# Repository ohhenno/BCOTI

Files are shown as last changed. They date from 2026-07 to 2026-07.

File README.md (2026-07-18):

# BCOTI (Budget-Clip-On-Thermal-Imager Remix**)
The current version uses a 256x192@12um sensor with a 4mm OR 9.1mm lens. This combined with the LZE039 and 10mm or 25mm DCX lens.









# BCOTI Fork — Parts List

Quick BOM with EU and US buy links per part.

| Part | Price | Description | EU Shop | US Shop |
|---|---|---|---|---|
| Thermal Core (Mini2, 256, 9.1mm or 4mm) | ~189€ | Thermal sensor core | [AliExpress](https://s.click.aliexpress.com/e/_ooB5Db9) | [Alibaba (Hdaniee)](https://www.alibaba.com/product-detail/HDANIEE-Series-Thermal-Imaging-Camera-Module_1601290252342.html) |
| 0.39" OLED Display | $110 / 98€ | Display + AV driver board | [AliExpress](https://s.click.aliexpress.com/e/_oCvDQUx) | [AliExpress US](https://www.aliexpress.us/item/3256809119244467.html) |
| ESP32-C3 | $1 / 2.6€ | Main controller board | [AliExpress](https://s.click.aliexpress.com/e/_oCkdBST) | [AliExpress US](https://www.aliexpress.us/item/3256808855552297.html) |
| 5V Boost Converter | $2 | Steps battery voltage up to 5V | [AliExpress](https://www.aliexpress.com/item/32800430445.html) | [Amazon](https://www.amazon.com/dp/B0836J8LR4) |
| 18350 Battery | ~$7 / ~3.50€ | Power source, button-top preferred | [AliExpress](https://de.aliexpress.com/item/1005006794197560.html) | [Amazon](https://www.amazon.com/Nitecore-NI18350A-700mAh-Rechargeable-Battery/dp/B00ZASC06Y) |
| Battery Contacts | ~3€ (50pc) / ~$8 (10pc) | Spring terminals for battery holder | [AliExpress](https://www.aliexpress.com/i/1005002703811117.html) | [Amazon (Keystone)](https://www.amazon.com/KEYSTONE-BATTERY-SPRING-CONTACT-pieces/dp/B00LPOWFGM) |
| Rotary Pot 10k (thumbwheel) | ~$7 (5pc) | Brightness/scroll control | [AliExpress](https://www.aliexpress.com/w/wholesale-10k-rotary-potentiometer.html) | [Amazon](https://www.amazon.com/10K-Ohm-Thumbwheel-Potentiometer-Pack/dp/B015IQP2I0) |
| Momentary Buttons (assortment) | ~$9 (200pc) | Mixed-size push buttons for menu/power | [AliExpress](https://www.aliexpress.com/w/wholesale-momentary-push-button.html) | [Amazon](https://www.amazon.com/Oiyagai-200-Pcs-Tactile-Momentary-Assortment/dp/B07DG3VGZT) |
| M2.5 Allen Bolt (assortment) | ~16€ (140pc) / ~$10 (310pc) | Hex socket screws, mixed lengths | [AliExpress](https://www.aliexpress.com/item/32823580440.html) | [Amazon](https://www.amazon.com/Stainless-Steel-Socket-Screw-Assortment/dp/B0116RIAO8) |
| M2.5 Heat Set Inserts | ~10€ (100pc) / ~$8 (50pc) | Threaded brass inserts for 3D-printed housing | [CNCKitchen](https://cnckitchen.store/products/gewindeeinsatz-threaded-insert-m2-5-standard-100-stk-pcs) | [Amazon (initeq)](https://www.amazon.com/initeq-M2-5-0-45-M2-5-0-4-Threaded-Printing/dp/B077CJQ3J4) |
| Silicone Wire (30AWG) | ~2€ (10m) / ~$10 (6-color kit) | Internal wiring, multiple colors | [AliExpress](https://www.aliexpress.com/item/32719731059.html) | [Amazon](https://www.amazon.com/TUOFENG-30awg-Stranded-Wire-Kit/dp/B07G2SWB19) |
| 5mmD 25mmF DCX Lens | ~40€ / $41.61 | Periscope objective lens | [Edmund Optics EU](https://www.edmundoptics.eu/p/5mm-dia-x-25mm-fl-uncoated-double-convex-lens/18171/) | [Edmund Optics US](https://www.edmundoptics.com/p/5mm-dia-x-25mm-fl-uncoated-double-convex-lens/18171/) |
| 5x5x5mm Right-Angle Prism | 1.99€ | Periscope reflector | [AliExpress](https://s.click.aliexpress.com/e/_oBrJOrZ) ([backup](https://www.aliexpress.com/item/4001089104491.html)) | [AliExpress US](https://www.aliexpress.us/item/2255799866264049.html) |
| USB-C Connector Breakout | 2.25€ | Internal USB-C wiring / low-profile helmet cable | [AliExpress ("TYPE-C male 4P")](https://s.click.aliexpress.com/e/_oCcvkCx) | [Amazon (Treedix)](https://www.amazon.com/Treedix-Type-C-Breakout-Connector-Converter/dp/B096M2HQLK) |
| USB-C Port | 1.49€ | Charging port, "4P Black" variant | [AliExpress](https://www.aliexpress.com/w/wholesale-usb-type-c-4-pin.html) | [AliExpress US](https://www.aliexpress.us/item/1005005768848819.html) |

**Notes**
- AliExpress "EU" links use the standard `.com`/`s.click` storefront (EU warehouse pricing); "US" links use `aliexpress.us` where available for faster US shipping.
- Assortment kit prices are for the full kit, not per piece — you'll only need a handful of pieces from each.

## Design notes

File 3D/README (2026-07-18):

Choose the right version you are building as there are some differences. Make sure your Mini camera lens is correct and the DFX lens you buy match!!!

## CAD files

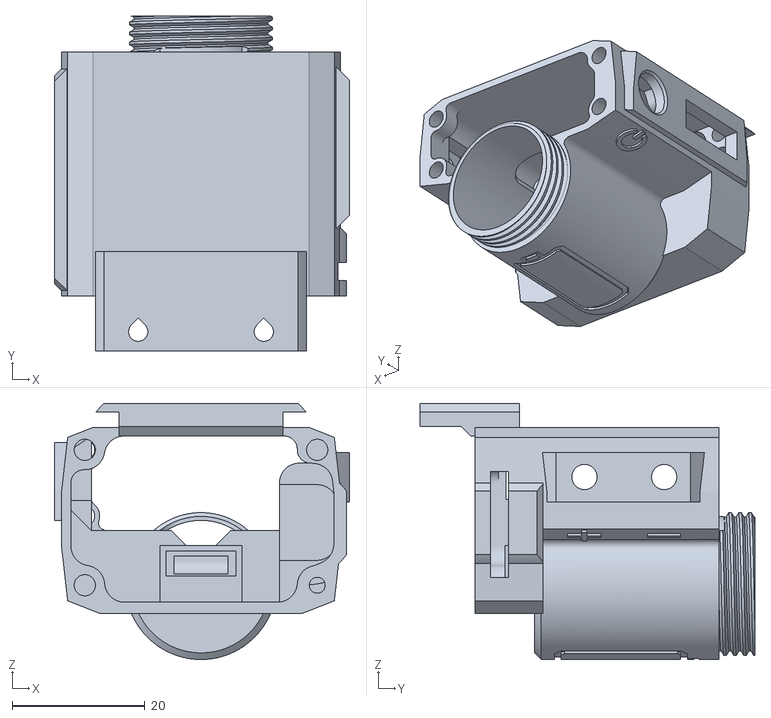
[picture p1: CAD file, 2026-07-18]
3D/mini256 9mm (narrow FOV)/main body 9mm lens.stl
44.5 x 50.5 x 38.6

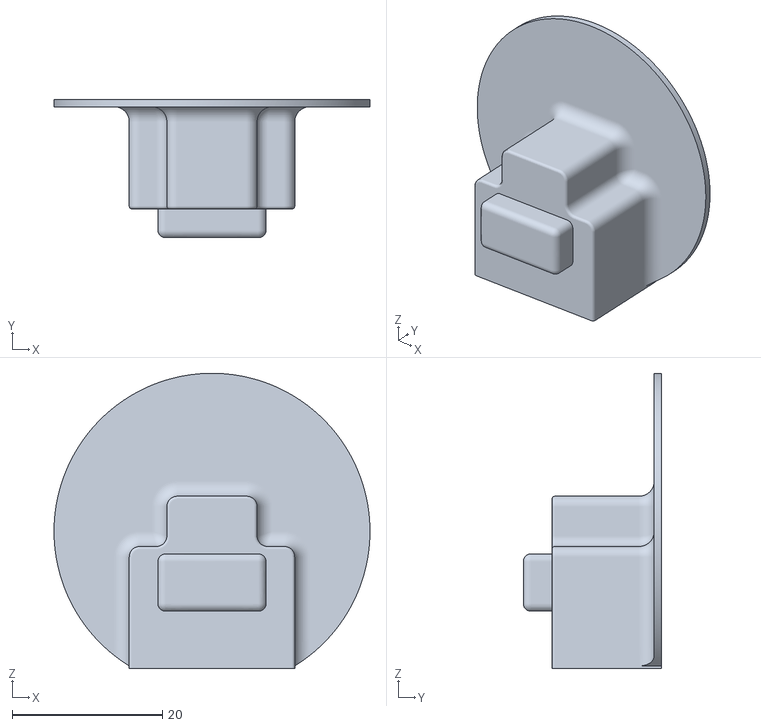
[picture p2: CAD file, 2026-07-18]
3D/mini256 4mm (wide FOV)/periscope cover (draft) 10mmF.stl
42.0 x 18.4 x 39.3

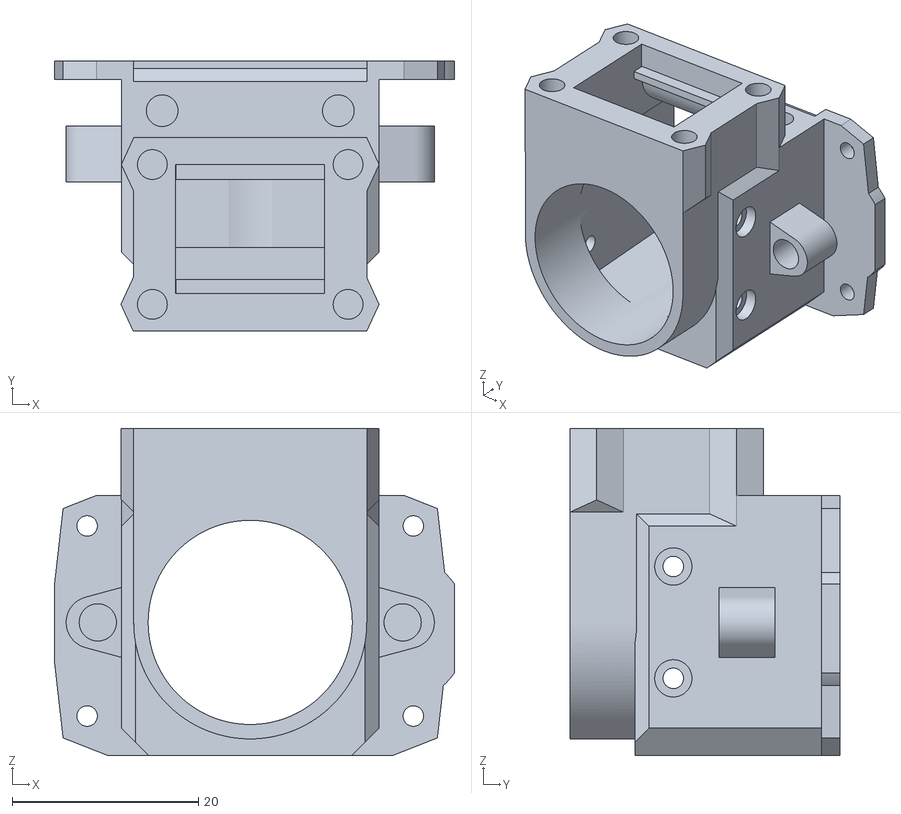
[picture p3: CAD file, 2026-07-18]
3D/mini256 9mm (narrow FOV)/front body 9mm.stl
42.9 x 29.0 x 35.1

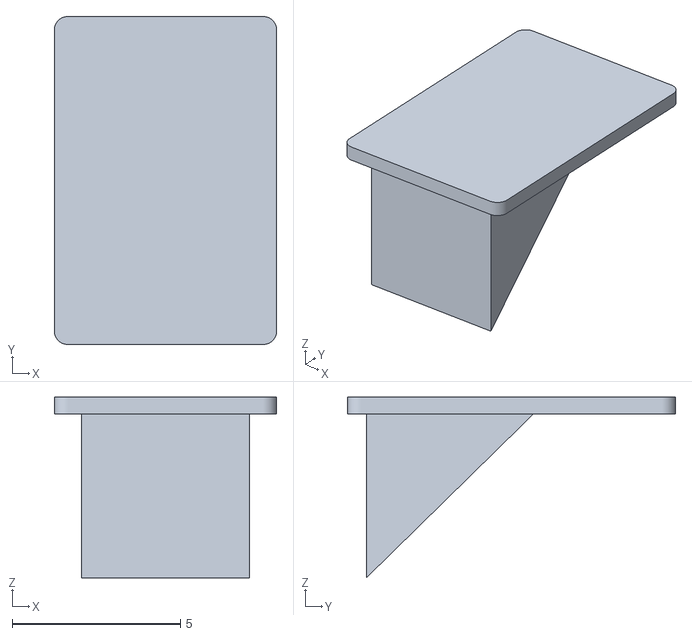
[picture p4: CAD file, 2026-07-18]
3D/mini256 4mm (wide FOV)/periscope hat.stl
6.60 x 9.74 x 5.36

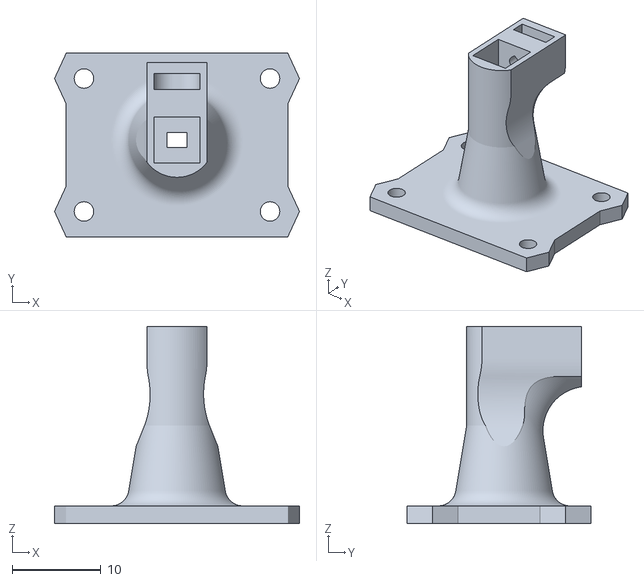
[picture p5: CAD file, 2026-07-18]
3D/mini256 9mm (narrow FOV)/periscope original 25mmF.stl
27.6 x 20.8 x 22.2

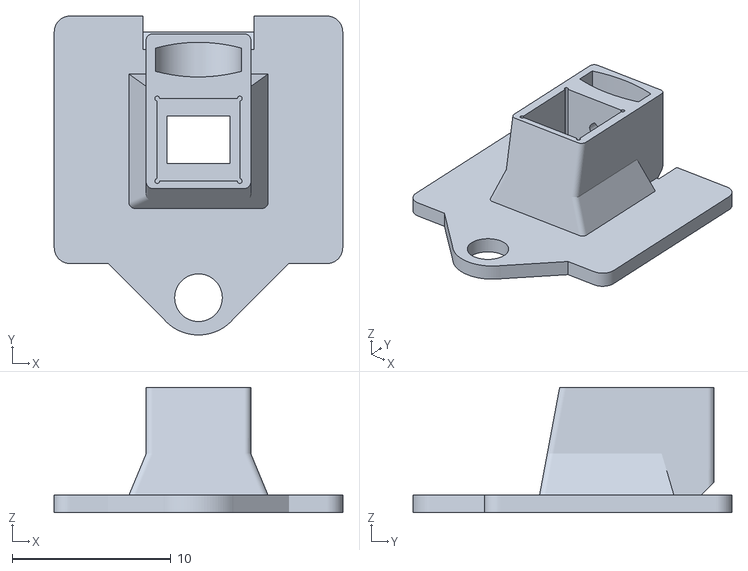
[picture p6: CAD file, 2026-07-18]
3D/mini256 4mm (wide FOV)/periscope 10mmF FOV.stl
18.2 x 20.1 x 7.89

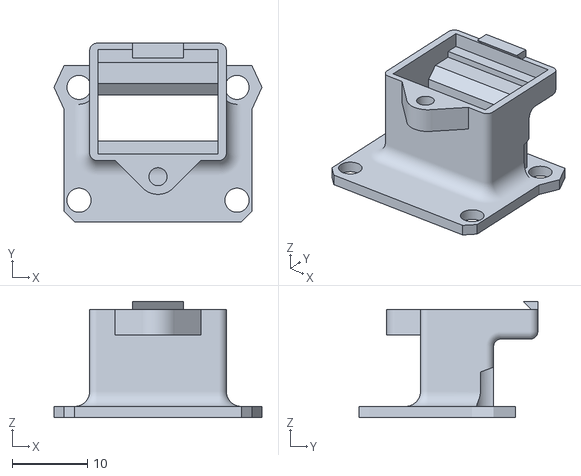
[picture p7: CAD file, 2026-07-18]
3D/mini256 4mm (wide FOV)/periscope spacer 10mmF FOV.stl
27.6 x 23.8 x 15.5

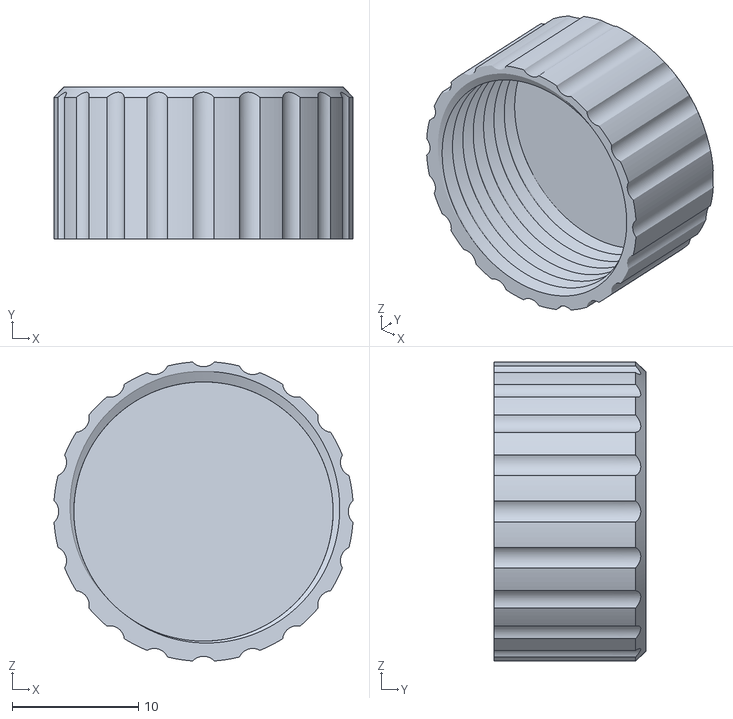
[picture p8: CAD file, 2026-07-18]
3D/mini256 9mm (narrow FOV)/bat cap.stl
23.7 x 12.0 x 23.7

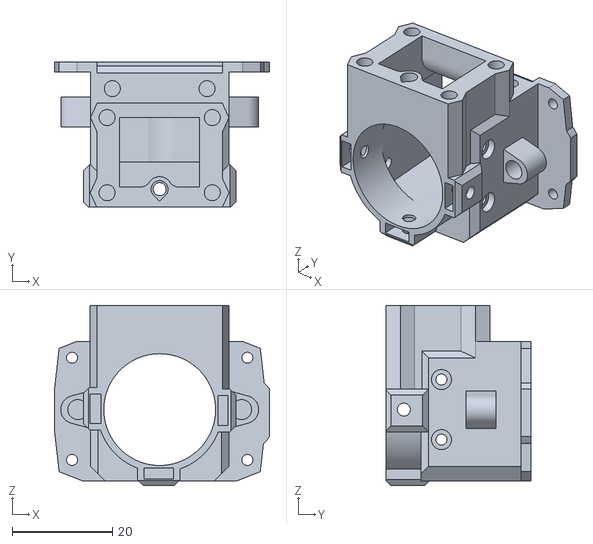
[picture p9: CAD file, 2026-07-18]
3D/mini256 4mm (wide FOV)/front body 4mm lens.stl
42.9 x 29.0 x 36.0

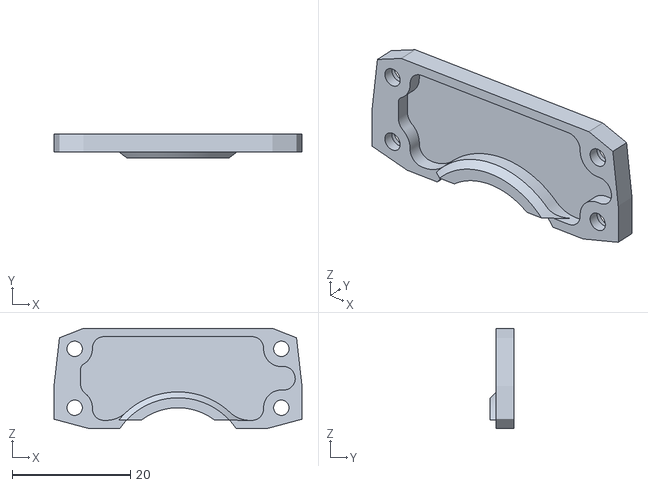
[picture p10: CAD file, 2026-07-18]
3D/mini256 9mm (narrow FOV)/back cover.stl
42.0 x 4.00 x 17.0

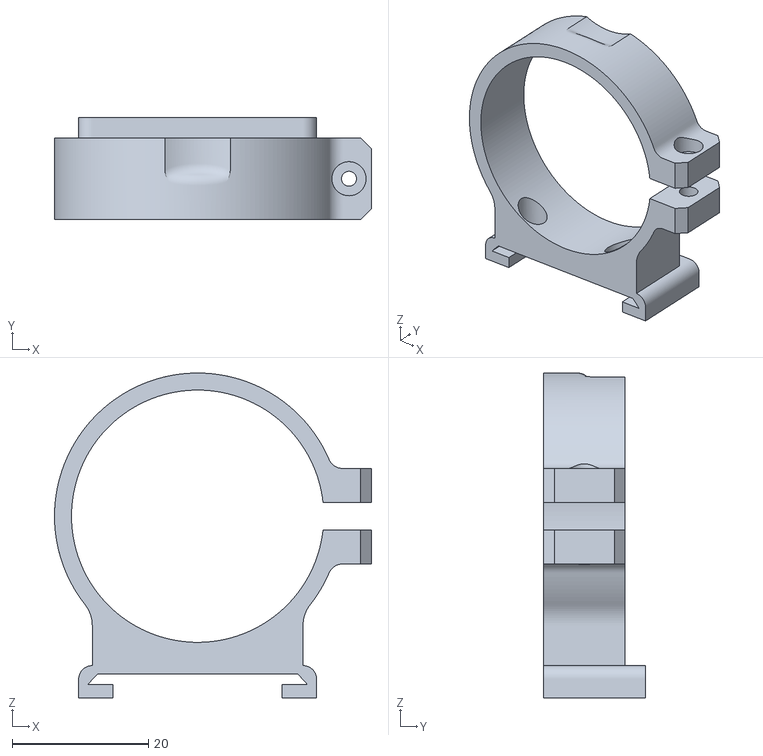
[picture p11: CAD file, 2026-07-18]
3D/mini256 9mm (narrow FOV)/lens attach.stl
46.5 x 15.0 x 47.7

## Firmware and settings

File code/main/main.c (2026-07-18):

#include <stdio.h>
#include <stdlib.h>
#include <stdint.h>
#include <stdbool.h>

#include "freertos/FreeRTOS.h"
#include "freertos/task.h"

#include "driver/gpio.h"
#include "driver/adc.h"

#include "nvs.h"
#include "nvs_flash.h"

#include "esp_wifi.h"
#include "esp_event.h"
#include "esp_netif.h"
#include "esp_http_server.h"

#include "Mini2.h"

// ============================================================
// WiFi Access Point settings
// Connect to this network, then open http://192.168.4.1
// ============================================================
#define WIFI_AP_SSID      "BCOTI-QC"
#define WIFI_AP_PASS      "thermal123"   // min 8 chars for WPA2
#define WIFI_AP_CHANNEL   1
#define WIFI_AP_MAX_CONN  4

static uint32_t last_click_time = 0;
static bool waiting_for_second_click = false;
static bool swallow_next_release = false;

static uint32_t mode_change_count = 0;
static uint32_t nuc_count = 0;
static uint32_t pan_count = 0;
static uint32_t brightness_count = 0;

static bool test_up = false;
static bool test_down = false;
static bool test_left = false;
static bool test_right = false;
static bool test_center = false;

static bool test_zoom = false;
static bool test_mode = false;
static bool test_nuc = false;
static bool test_brightness = false;

static int adc_min = 4095;
static int adc_max = 0;

#define DOUBLE_WINDOW_MS 400

#define PIN_CENTER     GPIO_NUM_0
#define PIN_LEFT       GPIO_NUM_3
#define PIN_UP         GPIO_NUM_10
#define PIN_RIGHT      GPIO_NUM_9
#define PIN_DOWN       GPIO_NUM_8

#define PIN_UART_TX    GPIO_NUM_1
#define PIN_UART_RX    GPIO_NUM_2

#define PAN_REPEAT_MS      40
#define TUNE_REPEAT_MS     60
#define SAVE_DELAY_MS    2000
#define NUC_PRESS_MS     3000
#define CENTER_PRESS_MS  6000

#define DEBOUNCE_MS        30
#define DPAD_LOCKOUT_MS   150

#define BRIGHT_MIN_INTERVAL_MS 150
#define BRIGHT_DEADBAND         3

// "Double-max sweep" gesture: turn the brightness knob to its extreme,
// let it fall away, then hit that same extreme again within the window
// -- this cycles the active mode/preset, same trick as the center-button
// double click. Thresholds are on raw ADC counts (pre direction-reversal),
// so ENTER is the low-raw / max-brightness end. This runs off a fast,
// lightly-smoothed reading (see adc_fast below) rather than the heavily
// filtered adc_filtered used for brightness output -- that filter has a
// multi-sample settle time that was eating quick flicks to the end.
#define KNOB_GESTURE_ENTER_RAW   500    // fast-filtered ADC <= this = "at max"
#define KNOB_GESTURE_EXIT_RAW    700    // must rise above this to re-arm
#define KNOB_GESTURE_WINDOW_MS  1200    // whole gesture must land in this window

#define ZOOM_MIN      10      // 1.0x
#define ZOOM_MAX      20      // 2.0x
static uint8_t zoom_level = 10;

#define PAN_STEP            1

#define ALIGN_CENTER_X   128
#define ALIGN_CENTER_Y    96

#define ALIGN_X_MIN      116
#define ALIGN_X_MAX      140

#define ALIGN_Y_MIN       87
#define ALIGN_Y_MAX      105

static Mini2_t cam;

typedef struct
{
    enum PseudoColor pseudo_color;
    enum SceneMode scene_mode;
    uint8_t contrast;
    uint8_t edge;
    uint8_t detail;
} preset_t;

static preset_t presets[3] =
{
    {
        .pseudo_color = WHOT,
        .scene_mode = Highlight,
        .contrast = 100,
        .edge = 1,
        .detail = 55
    },

    {
        .pseudo_color = WHOT,
        .scene_mode = HighContrast,
        .contrast = 100,
        .edge = 1,
        .detail = 55
    },

    {
        .pseudo_color = WHOT,
        .scene_mode = Outline,
        .contrast = 100,
        .edge = 1,
        .detail = 50
    }
};

// Default startup configuration is preset index 2 (Outline mode).
// This only matters on a fresh boot with no saved NVS preference --
// load_settings() will override it with whatever preset was last
// saved, if any.
static uint8_t active_preset = 2;

// Live tuning state (what the camera is currently set to).
// Initialized from the active preset, edited live via the
// web UI, and copied back into presets[] on "save preset".
static uint8_t cur_contrast = 100;
static uint8_t cur_edge = 1;
static uint8_t cur_detail = 55;
static enum SceneMode cur_scene = Highlight;
static enum PseudoColor cur_palette = WHOT;
static enum FlipMode cur_flip = No_Flip;
static bool cur_cross = false;

static uint16_t zoom_x = 128;
static uint16_t zoom_y = 96;

static uint8_t brightness = 50;
static uint8_t last_brightness = 255;
static uint32_t last_brightness_cmd = 0;
static int adc_filtered = -1;

// Fast, lightly-smoothed ADC reading used only for the knob gesture below.
// adc_filtered (heavy 7/8 IIR) is deliberately slow so brightness output
// doesn't jitter; that same slowness meant it often never reached the
// gesture thresholds during a quick flick. This settles in ~1-2 samples
// instead of ~8, while still knocking down single-sample ADC noise.
static int adc_fast = -1;

// Knob "double-max sweep" mode-change gesture state.
// 0 = idle, 1 = hit max once (waiting for it to fall away),
// 2 = fell away (armed, waiting for the second max hit).
static uint8_t knob_gesture_stage = 0;
static uint32_t knob_gesture_deadline = 0;

// When false, the physical pot is ignored and the web
// brightness slider is in control.
static volatile bool knob_enabled = true;

static uint32_t last_pan_time = 0;
static uint32_t last_move_time = 0;

static bool settings_dirty = false;

static bool center_prev = false;
static uint32_t center_press_time = 0;
static uint32_t center_release_time = 0;

static uint32_t last_status_print = 0;

// ============================================================
// Web -> main loop mailbox. HTTP handlers ONLY write these;
// the main loop is the only task that talks to the camera
// UART, so commands stay serialized and paced.
// ============================================================
typedef struct
{
    volatile bool dirty;
    volatile int  val;
} wp_t;

static volatile int  web_x = -1;
static volatile int  web_y = -1;
static volatile int  web_z = -1;
static volatile bool web_xyz_dirty = false;

static wp_t wp_bright;
static wp_t wp_contrast;
static wp_t wp_detail;
static wp_t wp_edge;
static wp_t wp_scene;
static wp_t wp_palette;
static wp_t wp_flip;
static wp_t wp_cross;

static volatile bool web_nuc_req = false;
static volatile bool web_bgc_req = false;
static volatile int  web_preset_req = -1;
static volatile bool web_preset_save_req = false;
static volatile bool web_center_req = false;
static volatile bool web_save_req = false;
static volatile bool web_camsave_req = false;

static uint32_t millis(void)
{
    return xTaskGetTickCount() * portTICK_PERIOD_MS;
}

static int clampi(int v, int lo, int hi)
{
    if(v < lo) return lo;
    if(v > hi) return hi;
    return v;
}

// ------------------------------------------------------------
// Debounced button reader
// ------------------------------------------------------------
typedef struct
{
    gpio_num_t pin;
    bool stable;
    bool last_raw;
    uint32_t last_edge;
} btn_t;

static btn_t btn_up     = { .pin = PIN_UP };
static btn_t btn_down   = { .pin = PIN_DOWN };
static btn_t btn_left   = { .pin = PIN_LEFT };
static btn_t btn_right  = { .pin = PIN_RIGHT };
static btn_t btn_center = { .pin = PIN_CENTER };

static void btn_update(btn_t *b, uint32_t now)
{
    bool raw = (gpio_get_level(b->pin) == 0);

    if(raw != b->last_raw)
    {
        b->last_edge = now;
        b->last_raw = raw;
    }

    if(raw != b->stable &&
       (now - b->last_edge) >= DEBOUNCE_MS)
    {
        b->stable = raw;
    }
}

static void buttons_update(uint32_t now)
{
    btn_update(&btn_up, now);
    btn_update(&btn_down, now);
    btn_update(&btn_left, now);
    btn_update(&btn_right, now);
    btn_update(&btn_center, now);
}

static bool dpad_allowed(uint32_t now)
{
    if(btn_center.stable)
        return false;

    if((now - center_release_time) < DPAD_LOCKOUT_MS)
        return false;

    return true;
}

// ------------------------------------------------------------
// NVS persistence: position, presets, active preset
// ------------------------------------------------------------
static void save_position(void)
{
    nvs_handle_t nvs;

    if(nvs_open("thermal", NVS_READWRITE, &nvs) == ESP_OK)
    {
        nvs_set_u16(nvs, "x", zoom_x);
        nvs_set_u16(nvs, "y", zoom_y);
        nvs_commit(nvs);
        nvs_close(nvs);
    }
}

static void save_presets(void)
{
    nvs_handle_t nvs;

    if(nvs_open("thermal", NVS_READWRITE, &nvs) == ESP_OK)
    {
        nvs_set_blob(nvs, "presets", presets, sizeof(presets));
        nvs_set_u8(nvs, "preset", active_preset);
        nvs_commit(nvs);
        nvs_close(nvs);
    }
}

static void load_settings(void)
{
    nvs_handle_t nvs;

    zoom_x = 128;
    zoom_y = 96;

    if(nvs_open("thermal", NVS_READONLY, &nvs) == ESP_OK)
    {
        nvs_get_u16(nvs, "x", &zoom_x);
        nvs_get_u16(nvs, "y", &zoom_y);

        size_t len = sizeof(presets);
        preset_t tmp[3];

        if(nvs_get_blob(nvs, "presets", tmp, &len) == ESP_OK &&
           len == sizeof(presets))
        {
            memcpy(presets, tmp, sizeof(presets));
        }

        uint8_t p = 0;
        if(nvs_get_u8(nvs, "preset", &p) == ESP_OK && p < 3)
            active_preset = p;

        nvs_close(nvs);
    }

    if(zoom_x < ALIGN_X_MIN) zoom_x = ALIGN_X_MIN;
    if(zoom_x > ALIGN_X_MAX) zoom_x = ALIGN_X_MAX;

    if(zoom_y < ALIGN_Y_MIN) zoom_y = ALIGN_Y_MIN;
    if(zoom_y > ALIGN_Y_MAX) zoom_y = ALIGN_Y_MAX;
}

static void send_point_zoom(void)
{
    Mini2_set_point_zoom(
        &cam,
        zoom_x,
        zoom_y,
        zoom_level);

    test_zoom = true;
}

static void next_zoom_level(void)
{
    zoom_level++;

    if(zoom_level > ZOOM_MAX)
        zoom_level = ZOOM_MIN;

    printf("\nZOOM = %.1fx\n", zoom_level / 10.0f);

    send_point_zoom();
}

static void center_alignment(void)
{
    zoom_x = ALIGN_CENTER_X;
    zoom_y = ALIGN_CENTER_Y;

    printf("\nCENTER ALIGNMENT\n");

    send_point_zoom();

    pan_count++;

    settings_dirty = true;
    last_move_time = millis();
}

static void apply_preset(void)
{
    preset_t *p = &presets[active_preset];

    // Sync live tuning state to the preset
    cur_palette  = p->pseudo_color;
    cur_scene    = p->scene_mode;
    cur_contrast = p->contrast;
    cur_edge     = p->edge;
    cur_detail   = p->detail;

    printf("\nAPPLY PRESET %u\n", active_preset);

    Mini2_set_color_pallet(&cam, cur_palette);
    vTaskDelay(pdMS_TO_TICKS(50));

    Mini2_set_scene_mode(&cam, cur_scene);
    vTaskDelay(pdMS_TO_TICKS(50));

    Mini2_set_contrast(&cam, cur_contrast);
    vTaskDelay(pdMS_TO_TICKS(50));

    Mini2_set_edge_enhancment(&cam, cur_edge);
    vTaskDelay(pdMS_TO_TICKS(50));

    Mini2_set_detail_enhancement(&cam, cur_detail);
    vTaskDelay(pdMS_TO_TICKS(50));

    printf("Preset applied\n");
}

static void next_preset(void)
{
    active_preset++;

    if(active_preset >= 3)
        active_preset = 0;

    mode_change_count++;

    printf("\nNEXT PRESET = %u\n",
           active_preset);

    apply_preset();

    test_mode = true;
}

static void setup_gpio(void)
{
    gpio_config_t io = {
        .mode = GPIO_MODE_INPUT,
        .pull_up_en = GPIO_PULLUP_ENABLE,
        .pull_down_en = GPIO_PULLDOWN_DISABLE,
        .intr_type = GPIO_INTR_DISABLE,
        .pin_bit_mask =
            (1ULL << PIN_CENTER) |
            (1ULL << PIN_LEFT)   |
            (1ULL << PIN_RIGHT)  |
            (1ULL << PIN_UP)     |
            (1ULL << PIN_DOWN)
    };

    gpio_config(&io);
}

static void setup_adc(void)
{
    adc1_config_width(ADC_WIDTH_BIT_12);
    adc1_config_channel_atten(
        ADC1_CHANNEL_4,
        ADC_ATTEN_DB_11);
}

// Watches the fast knob position for a quick max -> away -> max sweep
// and cycles the active preset when it sees one. Runs every pass (even
// when the web UI has taken over brightness) so the gesture state resets
// cleanly the moment "knob" control is handed back.
static void update_knob_gesture(int fast_raw)
{
    uint32_t now = millis();

    if(!knob_enabled)
    {
        knob_gesture_stage = 0;
        return;
    }

    if(knob_gesture_stage != 0 && now > knob_gesture_deadline)
        knob_gesture_stage = 0;   // took too long, gesture timed out

    switch(knob_gesture_stage)
    {
        case 0:   // idle, watching for the first max hit
            if(fast_raw <= KNOB_GESTURE_ENTER_RAW)
            {
                knob_gesture_stage = 1;
                knob_gesture_deadline = now + KNOB_GESTURE_WINDOW_MS;
            }
            break;

        case 1:   // hit max once, waiting to see it fall away
            if(fast_raw >= KNOB_GESTURE_EXIT_RAW)
            {
                knob_gesture_stage = 2;
                // Getting this far means we're mid-gesture -- give the
                // second hit the full window from right now rather than
                // eating into the time already spent on the first leg.
                knob_gesture_deadline = now + KNOB_GESTURE_WINDOW_MS;
            }
            break;

        case 2:   // armed, waiting for the second max hit
            if(fast_raw <= KNOB_GESTURE_ENTER_RAW)
            {
                knob_gesture_stage = 0;

                printf("\nKNOB DOUBLE-MAX SWEEP -> MODE CHANGE\n");

                next_preset();
            }
            break;
    }
}

static void update_brightness(void)
{
    int raw = adc1_get_raw(ADC1_CHANNEL_4);

    if(adc_filtered < 0)
        adc_filtered = raw;

    adc_filtered = (adc_filtered * 7 + raw) / 8;

    if(raw < adc_min) adc_min = raw;
    if(raw > adc_max) adc_max = raw;

    if(adc_fast < 0)
        adc_fast = raw;

    adc_fast = (adc_fast + raw) / 2;

    update_knob_gesture(adc_fast);

    // Web UI has taken over brightness control
    if(!knob_enabled)
        return;

    uint32_t now = millis();

    if(now - last_brightness_cmd < BRIGHT_MIN_INTERVAL_MS)
        return;

    // The pot is wired so that its raw ADC reading increases in the
    // opposite direction of the intended brightness travel. Invert
    // the filtered reading before mapping it to a 0-100% value.
    int adc_reversed = 4095 - adc_filtered;

    uint8_t b = (adc_reversed * 100) / 4095;

    if(abs((int)b - (int)last_brightness) >= BRIGHT_DEADBAND)
    {
        brightness = b;
        brightness_count++;

        printf("\nBRIGHTNESS CMD %u\n", brightness);

        Mini2_set_brightness(&cam, brightness);

        last_brightness = brightness;
        last_brightness_cmd = now;
        test_brightness = true;
    }
}

static void update_pan(void)
{
    uint32_t now = millis();

    if(!dpad_allowed(now))
        return;

    if(now - last_pan_time < PAN_REPEAT_MS)
        return;

    bool moved = false;

    if(btn_up.stable)
    {
        if(zoom_y > ALIGN_Y_MIN)
            zoom_y -= PAN_STEP;

        moved = true;
    }

    if(btn_down.stable)
    {
        if(zoom_y < ALIGN_Y_MAX)
            zoom_y += PAN_STEP;

        moved = true;
    }

    if(btn_left.stable)
    {
        if(zoom_x > ALIGN_X_MIN)
            zoom_x -= PAN_STEP;

        moved = true;
    }

    if(btn_right.stable)
    {
        if(zoom_x < ALIGN_X_MAX)
            zoom_x += PAN_STEP;

        moved = true;
    }

    if(!moved)
        return;

    zoom_x = clampi(zoom_x, ALIGN_X_MIN, ALIGN_X_MAX);
    zoom_y = clampi(zoom_y, ALIGN_Y_MIN, ALIGN_Y_MAX);

    pan_count++;

    printf("\nPAN CMD X=%u Y=%u Z=%.1fx\n",
           zoom_x,
           zoom_y,
           zoom_level / 10.0f);

    send_point_zoom();

    last_pan_time = now;
    last_move_time = now;
    settings_dirty = true;
}

static void update_center_button(void)
{
    bool current = btn_center.stable;
    uint32_t now = millis();

    if(current && !center_prev)
    {
        center_press_time = now;

        if(waiting_for_second_click &&
           (now - last_click_time) < DOUBLE_WINDOW_MS)
        {
            printf("DOUBLE CLICK\n");

            waiting_for_second_click = false;
            swallow_next_release = true;

            next_zoom_level();
        }
    }

    if(!current && center_prev)
    {
        center_release_time = now;

        uint32_t held = now - center_press_time;

        if(swallow_next_release)
        {
            swallow_next_release = false;
        }
        else if(held >= CENTER_PRESS_MS)
        {
            center_alignment();
        }
        else if(held >= NUC_PRESS_MS)
        {
            printf("\nNUC COMMAND\n");

            nuc_count++;

            Mini2_NUC(&cam);

            test_nuc = true;
        }
        else
        {
            waiting_for_second_click = true;
            last_click_time = now;
        }
    }

    if(waiting_for_second_click &&
       !current &&
       (now - last_click_time) >= DOUBLE_WINDOW_MS)
    {
        waiting_for_second_click = false;

        next_preset();
    }

    center_prev = current;
}

// ------------------------------------------------------------
// Apply pending web commands. Runs in the main loop.
// Tuning params are sent one per pass, min TUNE_REPEAT_MS
// apart, so slider drags can't flood the camera UART.
// ------------------------------------------------------------
static uint32_t last_tune_time = 0;
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
void app_main(void)
{
    esp_err_t ret = nvs_flash_init();

    if(ret == ESP_ERR_NVS_NO_FREE_PAGES ||
       ret == ESP_ERR_NVS_NEW_VERSION_FOUND)
    {
        nvs_flash_erase();
        nvs_flash_init();
    }

    setup_gpio();
    setup_adc();

    load_settings();

    wifi_init_softap();
    start_webserver();

    cam.uart_port = UART_NUM_1;
    cam.uart_tx   = PIN_UART_TX;
    cam.uart_rx   = PIN_UART_RX;
    cam.variant   = (Mini2_variant_t)Mini2_256;

    vTaskDelay(pdMS_TO_TICKS(5000));

    Mini2_init(&cam);

    vTaskDelay(pdMS_TO_TICKS(1000));

    printf("Applying startup mode...\n");

    apply_preset();

    vTaskDelay(pdMS_TO_TICKS(500));

    printf("Applying startup brightness...\n");

    update_brightness();

    vTaskDelay(pdMS_TO_TICKS(500));

    printf("Applying startup zoom...\n");

    Mini2_set_centre_zoom(&cam, 10);

    vTaskDelay(pdMS_TO_TICKS(250));

    for(int i = 0; i < 3; i++)
    {
        send_point_zoom();
        vTaskDelay(pdMS_TO_TICKS(50));
    }

    while(1)
    {
        uint32_t now = millis();

        buttons_update(now);

        qc_buttons();

        update_pan();
        update_center_button();
        update_brightness();
        process_web_commands();
        save_if_needed();

        qc_dashboard();

        vTaskDelay(pdMS_TO_TICKS(10));
    }
}

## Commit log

2026-07-18 Rename bcoti remix back cover.stl to back cover.stl
    [back cover.stl]
2026-07-18 Rename bcoti remix main body 4mm lens.stl to main body 4mm lens.stl
    [main body 4mm lens.stl]
2026-07-18 Rename front body main.stl to front body 4mm lens.stl
    [front body 4mm lens.stl]
2026-07-18 Rename front body main 4mm.stl to main body 4mm.stl
    [main body 4mm.stl]
2026-07-18 Rename periwscope cover 10mmF.stl to periscope cover (draft) 10mmF.stl
    [periscope cover (draft) 10mmF.stl]
2026-07-18 Rename bcoti remix main body 4mm lens.stl to main body 9mm lens.stl
    [main body 9mm lens.stl]
2026-07-18 Rename front body main 9mm.stl to front body 9mm.stl
    [front body 9mm.stl]
